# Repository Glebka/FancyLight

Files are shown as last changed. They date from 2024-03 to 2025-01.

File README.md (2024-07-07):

# FancyLight

FancyLight - an LED lamp powered by a Li-Ion battery, which can be found in used electronic cigarettes. It charges via a micro USB connector and is turned on and off using a touch button. A simple project to learn how to work with the TP4056 battery charging controller, a step-up DC-DC converter based on the SB6286 for powering LEDs, a touch switch controller based on the TTP223-BA6, as well as battery protection elements based on the DW01-P and dual MOSFET 8205A.

A touch switch controller is assembled on a separate PCB to improve touch sensing reliability.

## TODO

* Fix schematic and PCB:
    * Connect Q1's (SENSE) gate to GND via resistor
* Fix enclosure
    * Design mounting for the PCB for easier assembly
    * Fix the depth of mode selection pocket
    * Adjust heights because of PCB thickness increase
* (Minor) Update schematic and PCB
    * Introduce nRF module for BLE
    * Add wireless charger receiver as an alternative to USB-C

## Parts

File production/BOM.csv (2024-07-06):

Designator | Comment | Footprint | LCSC
C1,C3,C5,C7,C8 | 10u | Capacitor_SMD:C_0603_1608Metric | C96446
C2,C4 | 22uF | Capacitor_SMD:C_0805_2012Metric | C45783
C6,C9 | 0.1u | Capacitor_SMD:C_0603_1608Metric | C14663
D1,D2,D3,D4 | LED | LED_SMD:LED_PLCC_2835_Handsoldering | C210310
D5,D8,D9 | B5819W SL | Diode_SMD:D_SOD-123 | C8598
D6 | 1N5819WS | Diode_SMD:D_SOD-323 | C191023
D7 | CHRG LED | LED_SMD:LED_0603_1608Metric | C2286
D10 | STATUS LED | LED_SMD:LED_0603_1608Metric | C2286
Q1,Q2 | AO3400A | Package_TO_SOT_SMD:SOT-23 | C20917
R1 | 3k | Resistor_SMD:R_0603_1608Metric | C4211
R2,R3 | 22 | Resistor_SMD:R_0805_2012Metric | C17561
R4 | 5.1k | Resistor_SMD:R_0603_1608Metric | C23186
R5,R6,R12 | 1k | Resistor_SMD:R_0603_1608Metric | C21190
R7,R9 | 100k | Resistor_SMD:R_0603_1608Metric | C25803
R8,R10,R11,R14,R17,R18 | 10k | Resistor_SMD:R_0603_1608Metric | C25804
R13 | 5k | Resistor_SMD:R_0603_1608Metric | C23186
R15 | 330 | Resistor_SMD:R_0603_1608Metric | C23138
RN1 | 470 | Resistor_SMD:R_Array_Convex_4x0603 | C25510
U1 | APSWPA3015S4R7MTF | kicad_lceda:IND-SMD_L3.0-W3.0 | C5363870
U2 | SB6286 | Package_TO_SOT_SMD:SOT-23-6 | C157668
U3 | TP4056 | TP4056:SOP127P600X175-9N | C16581
U4 | XB3303A | kicad_lceda:SOT-23-3_L2.9-W1.3-P1.90-LS2.4-BR | C154937
U5 | HT7530S_C5451677 | kicad_lceda:SOT-23-3_L2.9-W1.3-P1.90-LS2.4-BR-CW | C5451677
U6 | ATtiny44A-M | Package_DFN_QFN:QFN-20-1EP_4x4mm_P0.5mm_EP2.6x2.6mm | C123718
USB1 | TYPE-C_6P | kicad_lceda:TYPE-C-SMD_TYPE-C-6P | C456012

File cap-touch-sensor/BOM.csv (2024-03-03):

Comment | Designator | Footprint | LCSC
5-10pF | C1 | Capacitor_SMD:C_0603_1608Metric | C37474
0.1u | C2 | Capacitor_SMD:C_0603_1608Metric | C14663
TTP223-BA6 | U1 | Package_TO_SOT_SMD:SOT-23-6 | C1693666

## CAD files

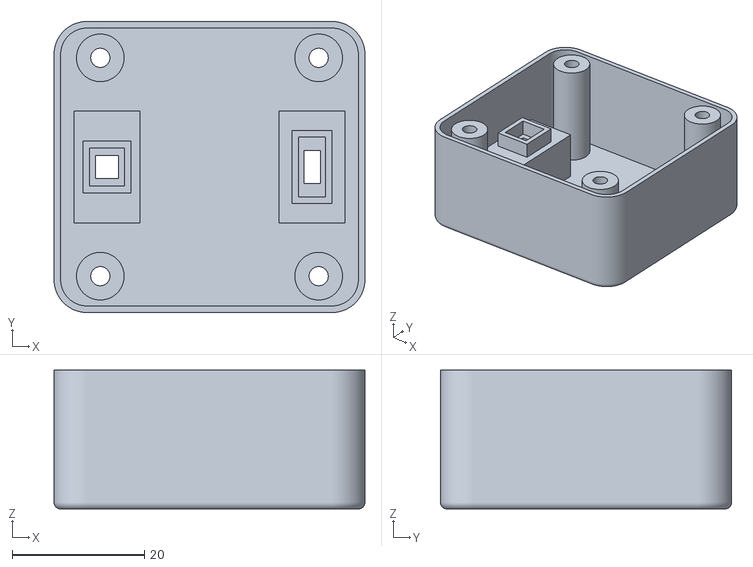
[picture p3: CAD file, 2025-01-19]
cad/fancy-light-v3.1-AssemblyBottomPart.stl
47.0 x 44.0 x 21.0

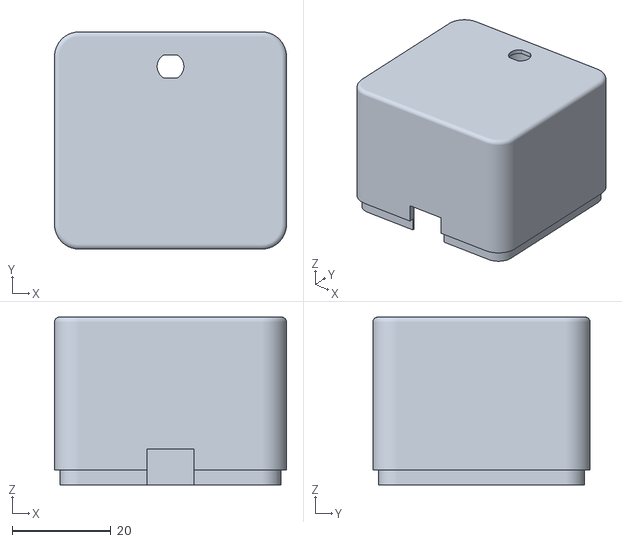
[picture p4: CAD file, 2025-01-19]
cad/fancy-light-v3.1-AssemblyTopPart.stl
47.0 x 44.0 x 34.0

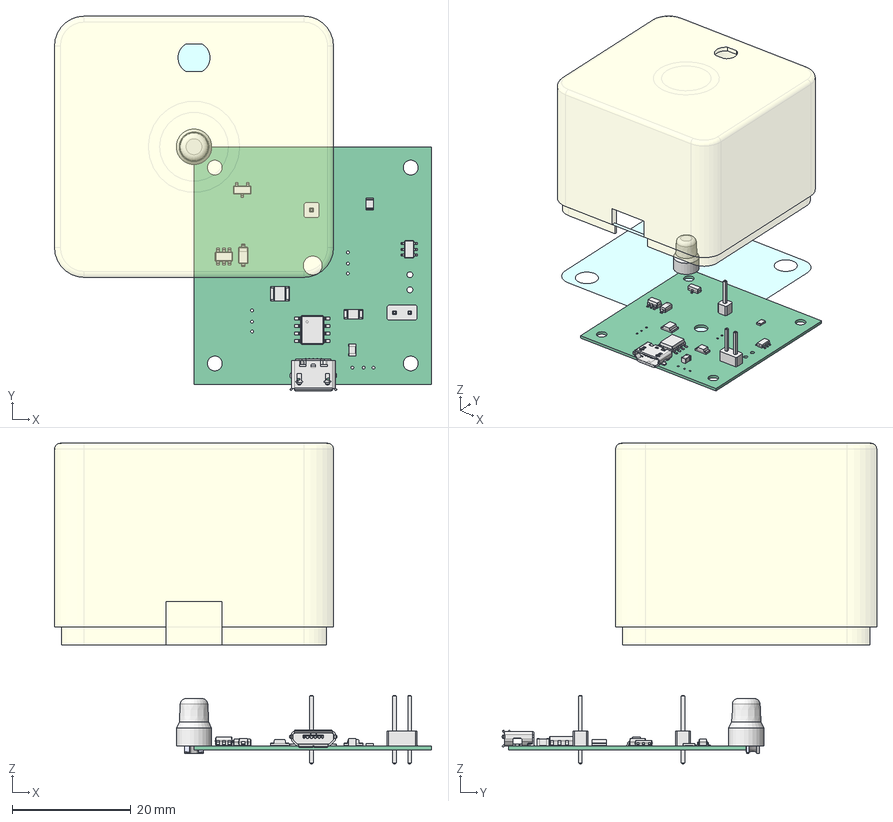
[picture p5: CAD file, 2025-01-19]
cad/fancy-light-v3.FCStd
63.5 x 63.1 x 54.0 mm
TopPart
Feet
LQH32CH2R2M23L
LQH32CH2R2M23L001
LQH32CH2R2M23L002
LQH32CH2R2M23L003
LQH32CH2R2M23L004
LQH32CH2R2M23L005
LQH32CH2R2M23L006
Pcb_f561
D6_LED_1206_3216Metric_18d98085dafd
C4_C_0805_2012Metric_49ea25723d70
R8_R_0805_2012Metric_290169979207
SW1_PinHeader_2x01_P254mm_Vertical_6490524a4e76
D3_LED_1210_3225Metric_88487c8b585e
J1_USB_Micro-B_Molex_47346-0001_8d1c2ae3cd0b
D5_D_SOD_123_89792e3b4ce5
U2_PowerIntegrations_SO_8_bd33549491cc
J2_PinHeader_1x01_P254mm_Vertical_95d08ce8a62d
U1_SOT_23_6_f766899ffb05
U5_TSOT_23_6_6eb4c45ecf4f
Q1_SOT_23_9d9a3cd09222
_Element
_Element003

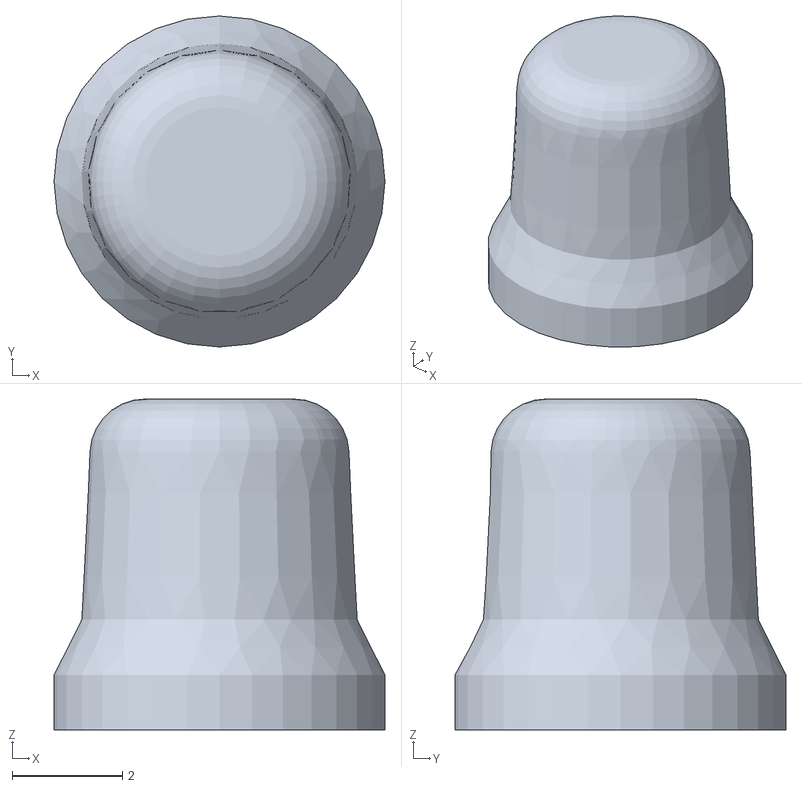
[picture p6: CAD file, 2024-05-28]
cad/fancy-light-v3-Feet.stl
6.00 x 6.00 x 6.00

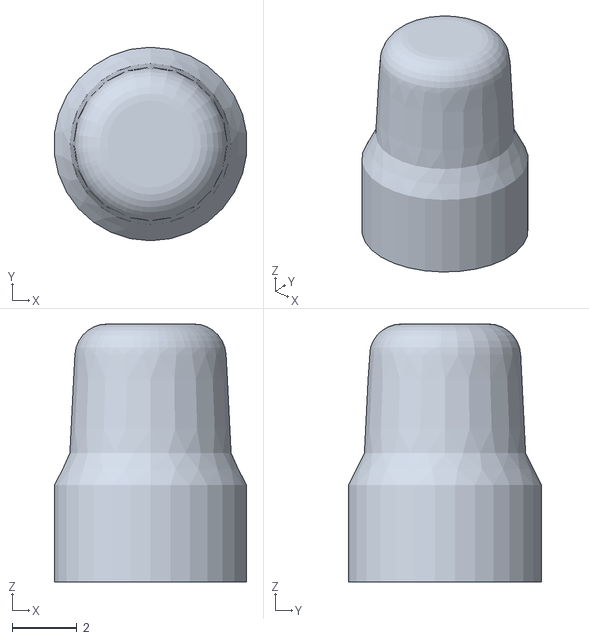
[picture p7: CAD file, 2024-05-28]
cad/fancy-light-v3-Feet-1.stl
5.97 x 6.00 x 8.00

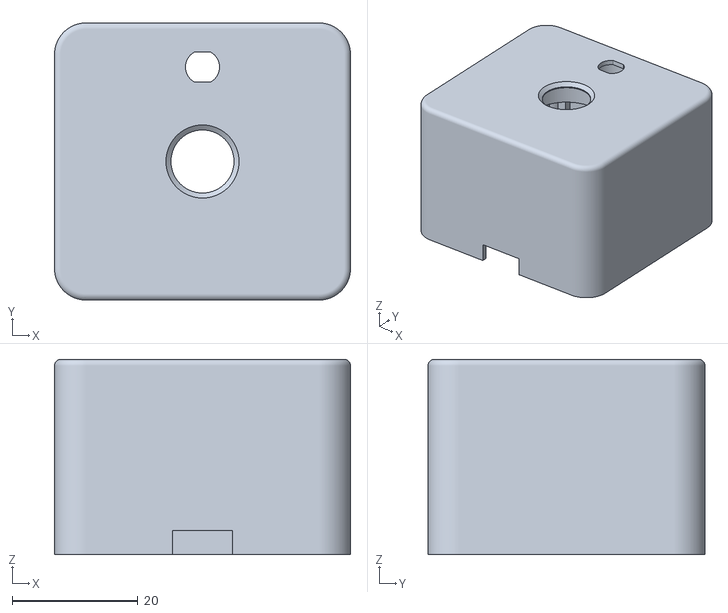
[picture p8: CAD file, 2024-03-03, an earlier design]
cad/fancy-light-v3-AssemblyTopPart.stl
47.0 x 44.0 x 31.0

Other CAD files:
cad/fancy-light-v3-AssemblyBottomPart.stl

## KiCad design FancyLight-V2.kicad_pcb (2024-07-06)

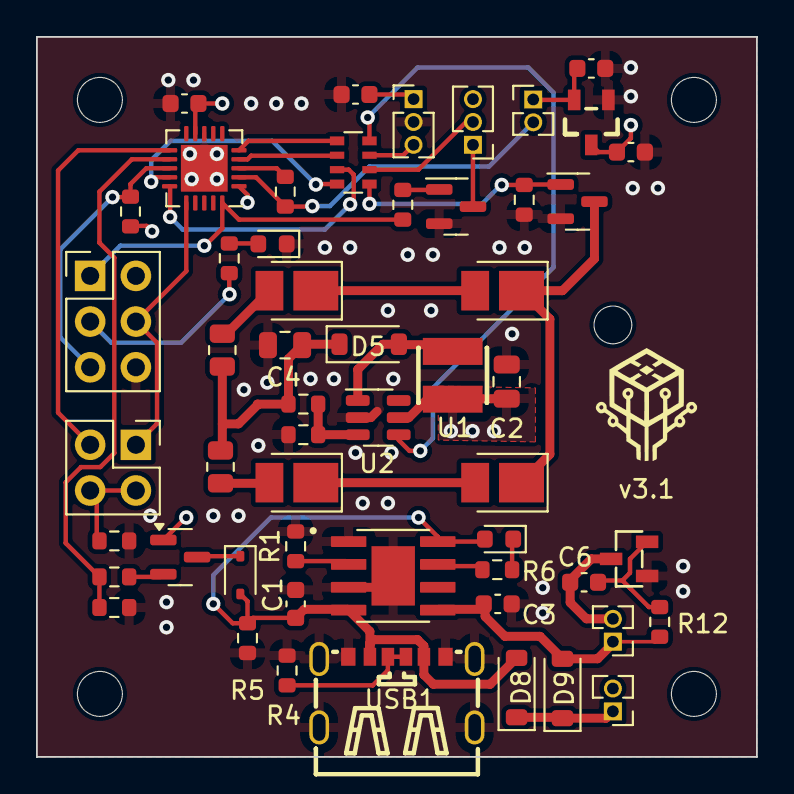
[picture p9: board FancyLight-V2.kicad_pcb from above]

Board: 4 copper layers, 40.0 x 40.0 mm, 59 parts (0 on the bottom side), 42 nets.

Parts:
BT1: 1000 mAh; PinHeader_1x02_P1.27mm_Vertical
C1, C3, C5, C7, C8: 10u; C_0603_1608Metric
C2, C4: 22uF; C_0805_2012Metric
C6, C9: 0.1u; C_0603_1608Metric
D1, D2, D3, D4: LED; LED_PLCC_2835_Handsoldering
D5, D8, D9: B5819W SL; D_SOD-123
D6: 1N5819WS; D_SOD-323
D7: CHRG LED; LED_0603_1608Metric
D10: STATUS LED; LED_0603_1608Metric
H1, H2, H3, H4: MountingHole_2.5mm
H5: MountingHole_2.1mm
J1: ISP; PinHeader_2x03_P2.54mm_Vertical
J2: TOUCH; PinHeader_1x03_P1.27mm_Vertical
J3: MODE; PinHeader_2x02_P2.54mm_Vertical
Q1, Q2, Q3: AO3400A; SOT-23
R1: 3k; R_0603_1608Metric
R2, R3: 22; R_0805_2012Metric
R4: 5.1k; R_0603_1608Metric
R5, R6, R12: 1k; R_0603_1608Metric
R7, R9: 100k; R_0603_1608Metric
R8, R10, R11, R14, R17, R18: 10k; R_0603_1608Metric
R13: 5k; R_0603_1608Metric
R15: 330; R_0603_1608Metric
R16: R_Photo; PinHeader_1x02_P1.27mm_Vertical
RN1: 470; R_Array_Convex_4x0603
SW1: ONOFF; PinHeader_1x02_P1.27mm_Vertical
U1: APSWPA3015S4R7MTF; IND-SMD_L3.0-W3.0
U2: SB6286; SOT-23-6
U3: TP4056; SOP127P600X175-9N
U4: XB3303A; SOT-23-3_L2.9-W1.3-P1.90-LS2.4-BR
U5: HT7530S_C5451677; SOT-23-3_L2.9-W1.3-P1.90-LS2.4-BR-CW
U6: ATtiny44A-M; QFN-20-1EP_4x4mm_P0.5mm_EP2.6x2.6mm
U7: syn480r; PinHeader_1x03_P1.27mm_Vertical
USB1: TYPE-C_6P; TYPE-C-SMD_TYPE-C-6P

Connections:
3V: C7.1, C8.1, J2.1, R16.1, U5.3 (VOUT)
BAT+: BT1.1 (+), C3.1, D9.2 (A), R12.1, U3.5 (BAT)
BAT-: C1.2, C2.1, C3.2, C4.2, C5.2, C7.2, C8.2, C9.1, D10.1 (K), J1.6, J2.2, Q2.2 (S), Q3.2 (S), R1.2, R4.2, R5.1, R8.2, R9.2, R11.2, R18.1, U2.2 (GND), U3.1 (TEMP), U3.3 (GND), U3.9 (EP), U4.1 (VM), U5.1 (GND), U6.8 (GND), U6.21 (GND), USB1.7 (EH), USB1.A12 (GND), USB1.B12 (GND)
DCDC_EN: RN1.8 (R1.2), U2.4 (EN)
DRAIN: D3.1 (K), D4.1 (K), Q2.3 (D)
LED_PWR: C4.1, D5.1 (K), R2.2, R3.2, R7.1
MISO: J1.1, R15.2, U6.20 (PA5)
MODE1: J1.4, J3.1, U6.16 (PA6)
MODE2: J3.3, U6.11 (XTAL1/PB0)
unnamed: BT1.2 (-), C6.2, U4.3 (GND)
unnamed: D1.2 (A), R2.1
unnamed: D1.1 (K), D3.2 (A)
unnamed: D2.2 (A), R3.1
unnamed: D2.1 (K), D4.2 (A)
unnamed: D5.2 (A), U1.2, U2.1 (SW)
unnamed: C1.1, D6.2 (A), D7.2 (A), D8.2 (A), R5.2, U3.4 (VCC), U3.8 (CE), USB1.A9 (VBUS), USB1.B9 (VBUS)
unnamed: D6.1 (K), Q1.3 (D)
unnamed: D7.1 (K), R6.2
unnamed: D8.1 (K), D9.1 (K), SW1.1 (A)
unnamed: D10.2 (A), R13.2
unnamed: J3.2, J3.4, R18.2
unnamed: Q1.2 (S), R10.1
unnamed: Q3.3 (D), U7.1 (GND)
unnamed: RN1.1 (R1.1), U6.5 (AREF/PA0)
unnamed: RN1.2 (R2.1), U6.4 (PA1)
unnamed: RN1.3 (R3.1), U6.15 (PA7)
unnamed: RN1.4 (R4.1), U6.14 (PB2)
unnamed: R7.2, R8.1, U2.3 (FB)
unnamed: R1.1, U3.2 (PROG)
unnamed: R6.1, U3.7 (~CHRG)
unnamed: C6.1, R12.2, U4.2 (VDD)
unnamed: R17.2, U6.3 (PA2)
unnamed: R16.2, R17.1, U6.2 (PA3)
unnamed: R4.1, USB1.A5 (CC1), USB1.B5 (CC2)
PWM: Q2.1 (G), R9.1, RN1.5 (R4.2)
RST: J1.5, R14.1, U6.13 (~RESET/PB3)
R_EN: Q3.1 (G), R15.1
R_TRIG: RN1.6 (R3.2), U7.2 (DAT)
SCK: J1.3, R13.1, U6.1 (PA4)
SENSE: R10.2, R11.1, U6.12 (XTAL2/PB1)
TRIG: J2.3, RN1.7 (R2.2)
VBAT: C2.2, C5.1, C9.2, J1.2, Q1.1 (G), R14.2, SW1.2 (B), U1.1, U2.5 (IN), U5.2 (VIN), U6.9 (VCC), U7.3 (VCC)

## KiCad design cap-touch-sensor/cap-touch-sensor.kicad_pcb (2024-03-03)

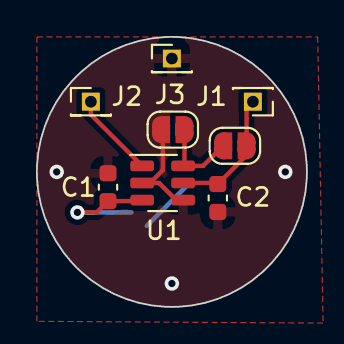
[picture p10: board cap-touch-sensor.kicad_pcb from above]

Board: 2 copper layers, 15.0 x 15.0 mm, 9 parts (1 on the bottom side), 5 nets.

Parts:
C1: 5-10pF; C_0603_1608Metric
C2: 0.1u; C_0603_1608Metric
J1: VBAT; PinHeader_1x01_P1.27mm_Vertical
J2: TOG; PinHeader_1x01_P1.27mm_Vertical
J3: GND; PinHeader_1x01_P1.27mm_Vertical
JP1, JP2: SolderJumper_2_Open; SolderJumper-2_P1.3mm_Open_RoundedPad1.0x1.5mm
TP4: SENSE; TestPoint_Pad_D4.0mm
U1: TTP223-BA6; SOT-23-6

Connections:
GND: C1.2, C2.2, J3.1, JP2.1 (A), U1.2 (VSS), U1.4 (AHLB)
unnamed: JP1.1 (A), JP2.2 (B), U1.6 (TOG)
unnamed: C1.1, TP4.1, U1.3 (I)
TOGGLE: J2.1, U1.1 (Q)
VBAT: C2.1, J1.1, JP1.2 (B), U1.5 (VDD)

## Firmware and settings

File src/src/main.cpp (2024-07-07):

#include <avr/power.h>
#include <avr/sleep.h>
#include <Arduino.h>

#include "common.hpp"
#include "config.hpp"
#include "power_control.hpp"
#include "touch_control.hpp"
#include "illumination_control.hpp"
#include "brightness_control.hpp"
#include "fsm.hpp"

void setup()
{
  cli();

  // disable ADC
  ADCSRA = 0;

  // turn off various modules
  power_all_disable();

  // but enable the necessary ones
  power_timer0_enable();
  power_timer1_enable();

  config::init();
  config::handle();

  power_control::init();
  touch_control::init();
  illumination_control::init();

  pinMode(LED_PIN, OUTPUT);
  digitalWrite(LED_PIN, LOW);

  sei();
  delay(5);
  power_control::powerDown();
}

void loop()
{
  config::handle();
  touch_control::handle();
  brightness_control::handle();
  illumination_control::handle();
  fsm::handleEvent(event::currentEvent);
}

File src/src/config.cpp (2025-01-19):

#include <Arduino.h>

#include "common.hpp"
#include "config.hpp"
#include "illumination_control.hpp"
#include "power_control.hpp"


namespace config {
    uint8_t feature_set = 0;

    void init() {
        pinMode(MODE1_PIN, OUTPUT);
        pinMode(MODE2_PIN, OUTPUT);
        digitalWrite(MODE1_PIN, LOW);
        digitalWrite(MODE2_PIN, LOW);
    }

    bool hasFeature(Feature feature) {
        return feature_set & feature;
    }

    void handle() {
        static bool mode1 = false;
        static bool mode2 = false;
        static uint8_t last_feature_set = 0;

        last_feature_set = feature_set;
        feature_set = 0;

        pinMode(MODE1_PIN, INPUT_PULLUP);
        pinMode(MODE2_PIN, INPUT_PULLUP);

        mode1 = !digitalRead(MODE1_PIN);
        mode2 = !digitalRead(MODE2_PIN);

        pinMode(MODE1_PIN, OUTPUT);
        pinMode(MODE2_PIN, OUTPUT);
        digitalWrite(MODE1_PIN, LOW);
        digitalWrite(MODE2_PIN, LOW);

        if (mode1 && mode2) {
            feature_set = BT_REMOTE_CONTROL;
        } else if (mode1) {
            feature_set = ILLUMINATION_DETECTION;
        } else {
            feature_set = MAINS_OUTAGE_DETECTION_USB;
        }
        
        if (feature_set != last_feature_set) {
            // re-init modules
            illumination_control::init();
            power_control::init();
        }
    }
}

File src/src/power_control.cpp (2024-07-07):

#include <Arduino.h>
#include <avr/sleep.h>

#include "common.hpp"
#include "illumination_control.hpp"
#include "power_control.hpp"
#include "brightness_control.hpp"

namespace power_control
{
    void init()
    {
        pinMode(DCDC_EN_PIN, OUTPUT);
        pinMode(PWM_PIN, OUTPUT);
        pinMode(SENSE_PIN, INPUT);
        digitalWrite(DCDC_EN_PIN, LOW);
        digitalWrite(PWM_PIN, LOW);
    }

    void turnLightOn()
    {
        digitalWrite(DCDC_EN_PIN, HIGH);
        analogWrite(PWM_PIN, brightness_control::intensity);
    }

    void turnLightOff()
    {
        digitalWrite(DCDC_EN_PIN, LOW);
        digitalWrite(PWM_PIN, LOW);
    }

    void powerDown()
    {
        set_sleep_mode(SLEEP_MODE_PWR_DOWN);
        cli();
        sleep_enable();
        sleep_bod_disable();
        sei();
        sleep_cpu();
    }

    void idle()
    {
        set_sleep_mode(SLEEP_MODE_IDLE);
        cli();
        sleep_enable();
        sleep_bod_disable();
        sei();
        sleep_cpu();
    }
}

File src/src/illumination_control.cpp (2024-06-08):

#include <avr/power.h>
#include <avr/wdt.h>
#include <Arduino.h>

#include "illumination_control.hpp"
#include "config.hpp"

inline void wdtEnable()
{
  wdt_enable(WDTO_4S);
  WDTCSR |= (1 << WDIE);
}

inline void adc_enable()
{
  digitalWrite(PHOTOR_SINK_PIN, LOW);
  power_adc_enable();
  ADMUX = (1 << MUX0) | (1 << MUX1); // select ADC3 (PA3) as input
  // enable ADC
  ADCSRA = (1 << ADEN)  // enable ADC
    | (1 << ADIE)       // enable ADC interrupt
    | (1 << ADPS1) | (1 << ADPS0)      // set prescaler to 16 (clock speed is 8 MHz / 16)
    ;
  DIDR0 = (1 << ADC3D); // disable digital input on ADC3
}

inline void adc_start()
{
  ADCSRA |= (1 << ADSC);
}

inline void adc_disable()
{
  ADCSRA = 0;
  power_adc_disable();
  digitalWrite(PHOTOR_SINK_PIN, HIGH);
}

namespace illumination_control
{

    uint16_t adc_value = 0;
    uint16_t high_illumination_threshold = 1000;
    event::Event last_event = event::NUM_EVENTS;
    unsigned long last_measurement_time = 0;

    void init()
    {
        if (config::hasFeature(config::ILLUMINATION_DETECTION))
        {
            pinMode(ADC_PIN, INPUT);
            pinMode(PHOTOR_SINK_PIN, OUTPUT);
            digitalWrite(PHOTOR_SINK_PIN, HIGH);
            wdtEnable();
        } else {
            pinMode(PHOTOR_SINK_PIN, OUTPUT);
            digitalWrite(PHOTOR_SINK_PIN, HIGH);
            pinMode(ADC_PIN, OUTPUT);
            digitalWrite(ADC_PIN, HIGH);
            wdt_disable();
        }
    }

    void update_high_illumination_threshold()
    {
        adc_enable();
        high_illumination_threshold = min(800, analogRead(ADC_ANALOG_PIN) + HYSTERESIS);
        adc_disable();
    }

    void reset()
    {
        last_measurement_time = 0;
        last_event = event::NUM_EVENTS;
        high_illumination_threshold = 800;
    }

    void handle()
    {
        if (last_measurement_time)
        {
            last_measurement_time = 0;
            if (adc_value < LOW_ILLUMINATION_THRESHOLD && last_event != event::LOW_ILLUMINATION)
            {
                event::currentEvent = event::LOW_ILLUMINATION;
                last_event = event::LOW_ILLUMINATION;
            }
            else if (adc_value > high_illumination_threshold && last_event != event::HIGH_ILLUMINATION)
            {
                event::currentEvent = event::HIGH_ILLUMINATION;
                last_event = event::HIGH_ILLUMINATION;
            } else {
                last_event = event::NUM_EVENTS;
            }
        }
    }
}

ISR(WDT_vect)
{
  WDTCSR |= (1 << WDIE);
  adc_enable();
  adc_start();
  digitalWrite(LED_PIN, HIGH);
}

ISR(ADC_vect)
{
  static uint8_t low = 0;
  static uint8_t high = 0;
  low = ADCL;
  high = ADCH;
  illumination_control::adc_value = (high << 8) | low;
  illumination_control::last_measurement_time = millis();
  adc_disable();
  digitalWrite(LED_PIN, LOW);
}

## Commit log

2024-03-03 Update CAD files and gitignore
    [BOM.csv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]
2024-05-28 feat: Add power control, config, touch control, brightness control, and illumination control modules
    [FancyLight-V2.kicad_sch, fancy-light-v3-Feet-1.stl, fancy-light-v3-Feet.stl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]
2024-06-08 Refactor touch switch controller for improved reliability
2024-07-06 Improve schematic and PCB
    [BOM.csv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]
2024-07-07 feat: Implement hardware PWM for brightness control
2025-01-19 feat: Update configuration and enhance brightness control logic
    [fancy-light-v3.1-AssemblyBottomPart.stl, fancy-light-v3.1-AssemblyTopPart.stl, fancy-light-v3.FCStd]
